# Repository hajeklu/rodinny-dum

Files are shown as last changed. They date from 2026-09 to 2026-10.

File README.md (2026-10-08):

# Rodinný dům Hájek · model v09

Interaktivní 3D studie bez garáže. Zachovává dohodnutou stranově převrácenou orientaci, střechu 45°, okapní přesah 1,00 m (dříve 1,20 m) a štítový 0,80 m. Střešní okna: VELUX FK08 66 × 140 cm, čtyři na jižní a dvě na severní straně.

## Obsah
- `index.html` — otočný 3D model s přepínači matné engoby a lesklé glazury i dvou rozsahů terasy
- `cad/` — OpenSCAD, OBJ a MTL exporty z varianty 09
- `povoleni/` — složka pro stavební povolení; zatím je v ní pouze informace, že podklad nebyl k dispozici
- `dokumentace/` — výkresy DSP: D1.2 půdorys 1NP a D1.3 půdorys 2NP (PDF)
- `.github/workflows/pages.yml` — nasazení GitHub Pages po pushi do větve `main`

Dřevěný obklad z průjezdu přechází na boční fasády a končí tam podle přepínače rovně s antracitovou lištou, střídavě nebo schody. Rohový sloupek je obložený dřevem jen do výšky HS portálu. Lesklá glazura odráží oblohu a slunce po jednotlivých taškách (vypouklý povrch, různé usazení, zaoblené hrany). Dům má nízký tmavý sokl končící pod HS portálem a střecha tenké oplechování štítu a hřebene. Přepínače ve „Variantách fasády“ zapínají antracitové šambrány a špalety oken, antracitovou linii patra ve štítech, svislé lamely na rohovém sloupku a ocelovou pergolu nad terasou; na prázdné stěně u fixu lze zobrazit dřevěné lamely nebo zelenou stěnu. Okapy jsou půlkulaté antracitové žlaby 150 mm se zarolovaným okrajem, okapnicí, háky, čely a kotlíky; na všech čtyřech rozích domu z nich vedou svody. Příjezdovka z tmavých žulových kostek vede podél domu na straně bez terasy a pokračuje průjezdem až po linii terasy. Tlačítko „Interiér přízemí“ skryje střechu a strop a ukáže zařízené přízemí podle D1.2 (obývák, jídelna, kuchyň s ostrůvkem, schodiště s krbem, koupelna, WC, předsíň, komora a technická místnost). Vstupní dveře mají vpravo (zvenku) prosklený světlík 60 cm na celou výšku, panty u boční stěny a madlo u světlíku; dveře z předsíně do chodby jsou v ose vstupních dveří a otevírají se do chodby. Skříň v předsíni je do stropu v barvě stěny bez úchytek, akcentem je jen dubová sedací nika s věšáky. Tlačítko „Interiér podkroví“ ukáže podkroví podle D1.3 s úpravou: ložnice v předním štítu rozdělená volně stojící stěnou na spací část a šatnu, bývalá šatna 2.03 jako koupelna k ložnici. Přepínač „Zadní část neobytná“ ukáže experimentální variantu: obytné podkroví končí kousek za hlavním domem, nad průjezdem a technickou místností zůstává neobytná půda za zateplenou příčkou s dveřmi z konce chodby (případně i skládací schody z technické místnosti); vedle ložnice s koupelnou jsou úklidová komora s pračkou a sušičkou, koupelna pro děti, dva dětské pokoje a komora z chodby. Okna VELUX jsou posunutá mimo příčky podkroví; venkovní žaluzie s lamelami C80 (přepínač) na HS, fixu, balkonových dveřích a oknech kuchyně a obýváku; jedna řada sněhových zábran u okapu na obou stranách střechy; přepínač „Večerní osvětlení“ ukáže podhledová světla, světla v průjezdu a nasvícení dřeva. Terasa je řešená jako „plovoucí“ dřevěná paluba téměř v úrovni prahu HS: prkna 140 mm souběžně s fasádou se střídanými spoji, tmavá stínová spára pod okrajem, dlouhý plovoucí schod s LED páskem a nášlapné kameny do zahrady, ocelové truhlíky s okrasnými travami a vícekmenným stromkem, jídelní stůl pro šest a lounge sezení. Stránka `kanalizace.html` ukazuje rozložené prostorové schéma odpadů a půdorysy s vývody pod deskou (K1, K2 u koupelny 1.05 a WC 1.04, K3 u kuchyně; skutečně položené KG 160, vývody DN 110). Porovnává varianty odkanalizování koupelny u ložnice: A (stoupačka v pilíři mezi okny a napojení na K3, doporučeno), B (podhled nad chodbou 1.06 do K2) a C (přečerpávání), s popisem tras k předání a riziky. V modelu přepínač „Stoupačka S2 v kuchyni“ ukáže, jak stoupačku z varianty A schovat: celý pilíř dostane předstěnu hlubokou 35 cm (líc s horními skříňkami) obloženou dubovými lamelami do stropu na akustickém filcu, S2 vede uvnitř asi 0,2 m od zdi za odnímatelným panelem, do předstěny je zapuštěná podsvícená vitrína v tenkém černém rámu a před ní plovoucí tmavá komoda s LED, nebo omítnutá šachta se sedací nikou obloženou dubem. Okna kuchyně a obýváku jsou 3,0 × 0,6 m (v povolení 0,7 m) s parapetem ve výšce pracovní desky (deska zajíždí do špalety až k rámu okna); celá kuchyň je tmavá bez úchytek (spodek, ostrůvek, vysoké skříně a horní skříňky nad oknem do stropu) s dubovou deskou. Stránka `vytapeni.html` je pracovní návrh podlahového topení podle projektu D.1.4: okruhy v přízemí a podkroví s plochami, roztečemi, výkony a průtoky pro nastavení rozdělovačů, rozdělovače R1 (vestavěná skříň v předsíni) a R2 (chodba podkroví nad ním), přívod z technické místnosti vrchem přes půdu nad průjezdem k R2 a stoupačkou do R1, okruhy nakreslené jako skutečná pokládka (bifilární šneky, topení i pod linkou a ostrůvkem), 6 zón regulace, hydraulické schéma s TČ, akumulací a zásobníkem TV, regulace (ekvitermní křivka v TČ, zóny na ESPHome, Home Assistant přes Modbus) a seznam kabelů k natažení. Přepínač „Podlaha v kuchyni, chodbě a předsíni“ porovná souvislý pás velkoformátové dlažby (kuchyň, chodba 1.06, předsíň, s rovným přechodem na dub na konci pilíře) s dubem v celém obytném prostoru. Přepínač „Průjezd · vstup bez schodu“ zvedne jen průjezd na −0,025 (jako v situaci C2 a řezu D1.6), takže se do domu i do technické místnosti jde bez schodu; okolo domu zůstává nízký terén s tmavým soklem. Do průjezdu vede od příjezdovky nájezd asi 3 m se sklonem 10 %, před vstupními i technickými dveřmi je liniový žlab do vsaku, vstupní dveře mají tmavý práh v ostění a na straně zahrady vedou z průjezdu dva široké plovoucí stupně ze světlého betonu se stínovou spárou a LED pod hranou (stejný jazyk jako schod terasy) a dál nášlapné kameny; s terasou přes celou stranu navazuje průjezd rovnou na palubu. Pro srovnání lze zobrazit nízký průjezd se schodem asi 0,35 m. Model zůstává vizualizační studií, ne prováděcí dokumentací ani podkladem pro statické posouzení.

## Zprovoznění Pages
V repozitáři otevři **Settings → Pages** a vyber **GitHub Actions** jako zdroj. Workflow potom nasadí stránku po pushi do `main`.

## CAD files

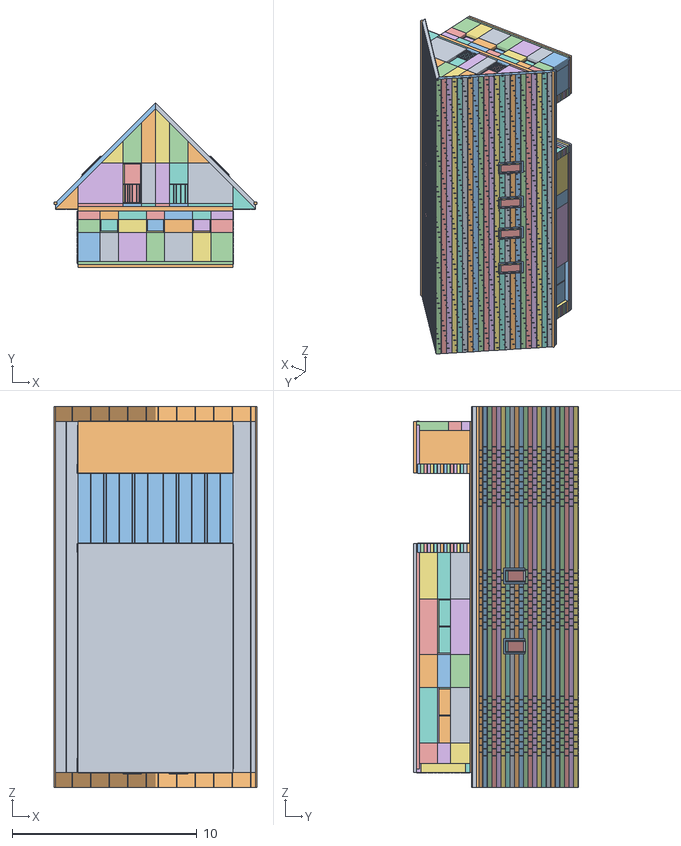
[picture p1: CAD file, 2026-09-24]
cad/dum-hajek.obj
10.9 x 8.90 x 20.6
Base_main
Base_technical
Floor_main
Floor_technical
Left_ground_0_0
Left_ground_0_1
Left_ground_0_2
Left_ground_1_0
Left_ground_1_2
Left_ground_2_0
Left_ground_2_1
Left_ground_2_2
Left_ground_3_0
Left_ground_3_2
Left_ground_4_0
Left_ground_4_1
Left_ground_4_2
Left_ground_window0_glass
Left_ground_window0_left
Left_ground_window0_right
Left_ground_window0_top
Left_ground_window0_bottom
Left_ground_window0_mullion
Left_ground_window1_glass
Left_ground_window1_left
Left_ground_window1_right
Left_ground_window1_top
Left_ground_window1_bottom
Left_ground_window1_mullion
Right_ground_0_0
Right_ground_0_1
Right_ground_0_2
Right_ground_0_3
Right_ground_0_4
Right_ground_1_0
Right_ground_1_4
Right_ground_2_0
Right_ground_2_1
Right_ground_2_2
Right_ground_2_3
Right_ground_2_4
Right_ground_3_0
Right_ground_3_1
Right_ground_3_3
Right_ground_3_4
Right_ground_4_0
Right_ground_4_1
Right_ground_4_2
Right_ground_4_3
Right_ground_4_4
Right_ground_window0_glass
Right_ground_window0_left
Right_ground_window0_right
Right_ground_window0_top
Right_ground_window0_bottom
Right_ground_window0_mullion
Right_ground_window1_glass
Right_ground_window1_left
Right_ground_window1_right
Right_ground_window1_top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

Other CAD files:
cad/dum-hajek.scad

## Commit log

2026-09-30 Realistic glazed tiles, half-round gutters and corner downpipes
    - Glaze shaded per tile: near-black base, Fresnel sky reflection, slightly convex
    tiles with random seating and rounded edges, sun glints breaking up tile by tile
    - Half-round 150 mm gutters with rolled bead, raised back, drip flashing, hooks,
    end caps and outlets
    - Anthracite downpipes at all four corners with offset under the soffit,
    brackets and gully
2026-09-30 Ground-floor interior after D1.2 with design layer
    - "Interiér přízemí" view hides roof and ceiling
    - Rooms 1.02–1.11 furnished per the DSP plan: kitchen with island, dining,
    living, U-shaped winder stair (18 steps), corner fireplace with firewood niche,
    bathroom, WC, hall, pantry, plant room with heat pump
    - Backlit oak slat TV wall, floor-to-ceiling slats at the stair, dark slatted
    planter dividing living and dining, pendants, plants
    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
2026-09-30 Optimised bathroom/WC layout toggle and interior refinements
    - "Podle projektu / Optimalizovaná" toggle: laundry moved to the plant room,
    shower screen on the bath, towel bench and open towel shelf in the bathroom
    - WC reworked: tiled installation wall with shelf, centred bowl, basin on the
    plumbing wall, wall cabinet; door kept clear
    - Hall: cleaning cupboard by the corridor door, wardrobe with seat niche and hooks
    - Living: planter behind the sofa moved to leave a passage by the window
2026-10-01 Attic interior after D1.3 with master suite in the front gable
    - "Interiér podkroví" view hides the roof; partitions clipped to the slopes
    - Master bedroom in 2.02 split by a free-standing wall (passages at both ends)
    into sleeping area with backlit oak slat headboard and walk-in wardrobe
    - Former wardrobe 2.03 becomes the en-suite (shower, vanity, WC under the slope)
    - Rooms 2.04–2.09, corridor with oak balustrade around the stair opening,
    landing bench; stair opening cut through the upper slab
2026-10-01 Roof windows clear of attic walls, upstairs laundry, blinds, snow guards, night lighting
    - VELUX positions moved off the attic partitions
    - Optimised layout: laundry in 2.05, bathroom 2.07 shared from the corridor
    - Exterior venetian blinds (C80 slats, guide rails, bottom rail) on HS, fix,
    gable doors and kitchen/living windows; attic ones hide with the upper floor
    - One row of snow guards above the eaves, kept below the roof windows
    - Evening lighting: soffit and passage downlights plus timber uplights as real
    point lights in the shader, warm lit windows and interior LEDs
2026-10-06 Kitchen and dining wall: dark kitchen with wall cabinets, slatted pier casing hiding S2
    - Kitchen in one dark handleless finish (base run, island, tall cabinet, wall
    cabinets from the window head to the ceiling); worktop runs into the window
    reveal as the inner sill; continuous oak floor through the open plan.
    - Living and kitchen windows 3.0 x 0.6 m with the sill at worktop height.
    - Pier between the windows: 35 cm casing flush with the wall cabinets, clad in
    oak slats to the ceiling, S2 inside about 0.2 m from the wall face, recessed
    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
2026-10-07 Underfloor heating plan, tiled service strip, lined doors, entrance sidelight and lighter hall
    - vytapeni.html: UFH layout for both floors (17 circuits, 6 zones, R1/R2, supply over the passage loft), controls and cabling for HA
    - Kitchen, corridor and hall floor: large-format tiles or oak by toggle
    - Pantry entrance as a hidden door in the kitchen cladding
    - All doors closed, lining frames in anthracite with oak leaves
    - Entrance door with a 60 cm sidelight, hinges on the side wall, handle by the sidelight
    - Hall door on axis with the entrance, wardrobe in wall colour with an oak seat niche
2026-10-08 Level entrance from a raised passage, garden steps
    - Passage raised to -0.025 under the floor (C2 / D1.6): ramp from the driveway, slot drains at the entrance and technical doors, threshold sill in the reveal
    - The rest of the house keeps the low terrain and the dark plinth; toggle to compare with the old low passage
    - Garden end of the passage: floating light concrete steps with LED and stepping stones
2026-10-14 Roof framing page, HS portal section with ring beam, shared Podklady menu, permit board
    - krov.html: parametric roof framing with 3D model, cross/long sections, plan,
    details, 2U240 box ridge beam on R1/R3 and a cut list
    - rez-vyska.html: HS portal side view with the IPE lintel cast into the ring beam
    - nav.js: one shared "Podklady" menu, soft-hidden on the 3D model page
    - index.html: permit dialog styled like the site board; export buttons removed
2026-10-14 Ridge beam on three frames with R2 in the corridor walls, correct permit number, drop CAD exports
    - krov.html: default is the DSP 2U200 ridge beam plus frame R2 whose posts sit in the
    corridor partitions; cross-section through R2, ridge splices at zero-moment points
    - index.html: permit case number 3518/2024/OSUZP/6/Pr-0332
    - remove cad/ exports (download buttons were already gone)
2026-10-15 Sun study, eye view, section cut, room areas, reading egg by the fix
    Orientation with compass, sun position and shadows for Krasny Les,
    chimney above the roof, heat pump behind the plant-room gable with its
    25 dB contour, eye-level walk-through, section planes and room labels
    with an area table against D1.2 and D1.3. Dropped ceiling over the HS
    and fix band with a strip over the island, curtain pocket, reading egg
    of oak slats with a hanging chair, entrance sidelight moved to the WC
    side, island shortened and moved as in D1.2 to free the pantry door.
2026-10-16 Tape measure, attic landing by the chimney, ring beam section over the HS
    Measure tool in the model: click two points to get the distance with its
    horizontal and vertical part, snapping to corners and edges. Attic
    landing: balustrade ends on the plastered chimney and continues along
    the top steps, bench with a fig along the rail so the corridor stays
    free. Section page: cross-section of the ring beam over the HS with the
    blind box, both IPE layouts and their insulation, and the plan of the
    ring beam rebars welded to the IPE ends.
2026-10-16 Wider hall door, 2.1 m door leaves, warm plaster soffit by default, MVHR intake and exhaust on separate facades
2026-10-18 Living-room AC hidden in the dropped ceiling by the HS, fan coil or split
2026-10-18 Finance page by construction stages with a stage drawdown card, dismissable duplicate checks; split AC by default
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2026-10-21 Ground-floor plan, MVHR and water pages on a shared drawing base; AC only as a cassette in the attic hallway
    - pudorys-1np.html with its print PDF: working ground-floor plan for the build (walls, partitions with set-out table, openings, doors, room legend, changes against D1.2)
    - rekuperace.html and voda.html, drawings on the shared base schema.js (house geometry, sheet frame, exploded view, P-01 penetrations, V-04 plant room)
    - AC only upstairs: one 4-way cassette fan coil on chilled water from the LG heat pump in the hallway ceiling at the stair head; nothing on the ground floor, which only has MVHR and floor cooling (mo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
    - nakup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
2026-10-22 Window heads of the fix and the HS in the ceiling finish, attic hallway view aimed at the cassette
    The head reveals take the finish of the dropped ceiling underside (plaster by default, or the wood boards), so it runs on to the frames; jambs and the pier stay white. The attic hallway eye view now looks straight at the cassette.
    — Claude (AI asistent)
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2026-11-01 Ceiling panel laying plan with two options over the passage - New page stropni-panely.html: draft laying plan S-01 for the ground-floor ceiling from Spiroll 250 hollow-core panels as input for the pa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
2026-11-03 House at the as-built size 8.3 × 11.9 m (walls flush with the measured slab)
    - The slab came out 8.3 × 11.9 m and the outer walls stand on its edge (DSP masonry 8.0 × 11.83, the pages used 8.0 × 12.0). Assumed: the slab grew 150 mm per side and the interior is set out as designed, so partitions, stair, chimney and the cast K1–K3 stay; cast items are to be measured on site
    - Rule on every page: left long wall stays, interior +150, right wall +300 (FIX keeps its 520 corner pier), from s 9 600 everything −100 (kitchen, corridor 1.06 and bathroom 1.05 100 shorter); ridge 150 higher over x 4 150, flat attic ceiling stays at +5.660 and gets 300 wider
    - 3D model: drawn in design coordinates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
2026-11-04 Stair trimmer VM2 rests on load-bearing wall P7
    - VM2 no longer hangs on panel 05 next to the chimney cut-out, where its pad sat on the strip the cut-out cuts off. It rests on P7, cantilevers 0.8 m along the cut-out under the end of that strip and keeps only the pad on 08
    - P7 is load-bearing (250 mm, P4-500, concrete sill), 150 mm longer toward the hall, its end on the chimney pad and stair strip from D1.1
    - stropni-panely: S-01, D5 and a redrawn D4, variant A text, laying order 04, VM1, 08, VM2, 05, 06, 07, loads (P7 ~50 kN, P9 ~25 kN) and steel tables, site steps and questions for the structural engineer
    - pudorys-1np: P7 row, wall and legend, 2 190 dimension moved off the wall end; 3D mo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
2026-11-05 README with screenshots of the model and drawings
    - New intro with a link to the live site and a large picture of the whole house
    - Gallery of six model views (ground floor and attic without the roof, eye-level views, evening, ceiling panels) and six drawings (ground-floor plan, S-01, roof section, MVHR, electrical and heating schemes), each linked to its page
    - Short note on running the site locally; the original content stays below under its own headings
    - 13 WebP screenshots in screenshots/ (1.5 MB)
    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
2026-11-06 Kitchen and living room windows O2, O3 as fixed glazing
    - pudorys-1np: O2 and O3 noted as fixed glazing in the frame, two panes with a mullion; change list item 5 says so; A3 PDF reprinted
    - index.html: kitchen description says the window is fixed (the model already draws frames without sashes)
    - README: fixed glazing with the reason (a sash adds about 5 cm of frame top and bottom on a 600 mm window); permit height corrected to 0,9 m
    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
2026-11-10 IPE 240 lintels with 300 mm bearing on every opening
    - pudorys-1np: O2 and O3 lintels 3 640 instead of 3 500 (rough opening 3 040 like HS, so 3 500 left only 230 mm bearing), FIX 2 640 instead of 2 500; every lintel shows its make-up (300 + opening + 300); HS no longer says the length comes from the statika (it prescribes only the profile); A3 PDF reprinted
    - nakup-zdeni (encrypted): IPE 4× 5,0 m over the passage (opening 4 200, as in the steel inquiry), 6× 3,64 m for HS, O2, O3, 2× 2,64 m for FIX; steel total ≈ 3,3 t
    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
2026-11-10 Plinth recessed 100 mm behind the facade
    - Below +0.24 (HS / fix threshold) the walls carry only the 100 mm XPS of the plinth instead of the 200 mm EPS, so the charcoal plinth sits 100 mm behind the facade and the recess turns every corner of the house and the plant room
    - Slab edges pulled back behind the plinth as well
    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
2026-11-11 Window review: lintel page, VELUX sun tunnel, corner window, metal balustrades
    - preklady.html (new, Podklady > Stavba): every outer wall and both gables course by course with lintels, ring beam and what does not fit; switch "Podle současných výkresů" / "Doporučená úprava" (lintels straight on course 10, small windows 1 000 × 700 moved 27 mm down with the difference in the sill underlay profile, D1 SOLBET NS 230, gable doors NS 140 in gable course 11, no ring beam in the gables)
    - stropni-panely: over the entrance D1 the system lintel SOLBET NS 230 stays; the lower ring beam over it carries the passage panels and the R3 posts (~3× Ø 14 at the bottom); notes, drawing D2 and the chec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
2026-11-12 Frameless ground-floor fixes in the model and the 1NP plan
    - 3D model: FIX, O2, O3 and the HS fixed field without a visible frame by default (toggle in Zobrazení, variants in Exteriér, ?fixy= links); O2 and O3 as one pane
    - Plan 1NP: hidden frames dashed, covered outside by the reveal EPS and inside by a 65 mm XPS/PIR board, ZB corner unchanged
    - FIX, HS, O2, O3 rough openings 170 mm wider (FIX and HS away from the corner), IPE lengths updated, head under the ring beam flagged
    - Reprinted A3 and A4 PDFs
    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
